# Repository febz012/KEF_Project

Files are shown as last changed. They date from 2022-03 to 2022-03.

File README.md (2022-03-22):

# KEF_Project
This repository consists of a series of IoT projects with LoRA

# 1)  Weather Station 
      A weather station constructed using Industrial grade sensors. 
      The data is collected periodically and transmitted to a capture station using LoRa.
      After the data is received at the capture station using a gateway,it is uploaded to the cloud using a Nodemcu/Raspberry Pi
      
      The following sensor data were collected
      *****************************************
      
      i)    Humidity and Temperature
      ii)   Wind Speed
      iii)  Wind Direction
      iv)   Rain Gauge
      v)    Barometric Pressure
      vi)   Dew Point
      vii)  Air Density
      
      Components used
      ****************
      
      i)    Atmega328P
      ii)   Nodemcu/Raspberry Pi
      iii)  SMD Resistors,Capacitors
      iv)   Max485 TTL Converter Module
      v)    CD4053 triple 2-channel MUX/DEMUX
      vi)   RF Module E32-868T30D
      vii)  Weather Station Sensors (Detailed list provided in repo)

# 2) LIDAR WATER LEVEL MEASURING UNIT
      Measure Water level of a well using Lidar and transmit the data to a capture station via LoRa.
      The data is then uploaded to a Cloud Storage and made availble on Internet.
      
      LIDAR WATER LEVEL MEASURING UNIT
      Measure Water level of a well using Lidar and transmit the data to a capture station via LoRa.
      The data is then uploaded to a Cloud Storage and made availble on Internet.

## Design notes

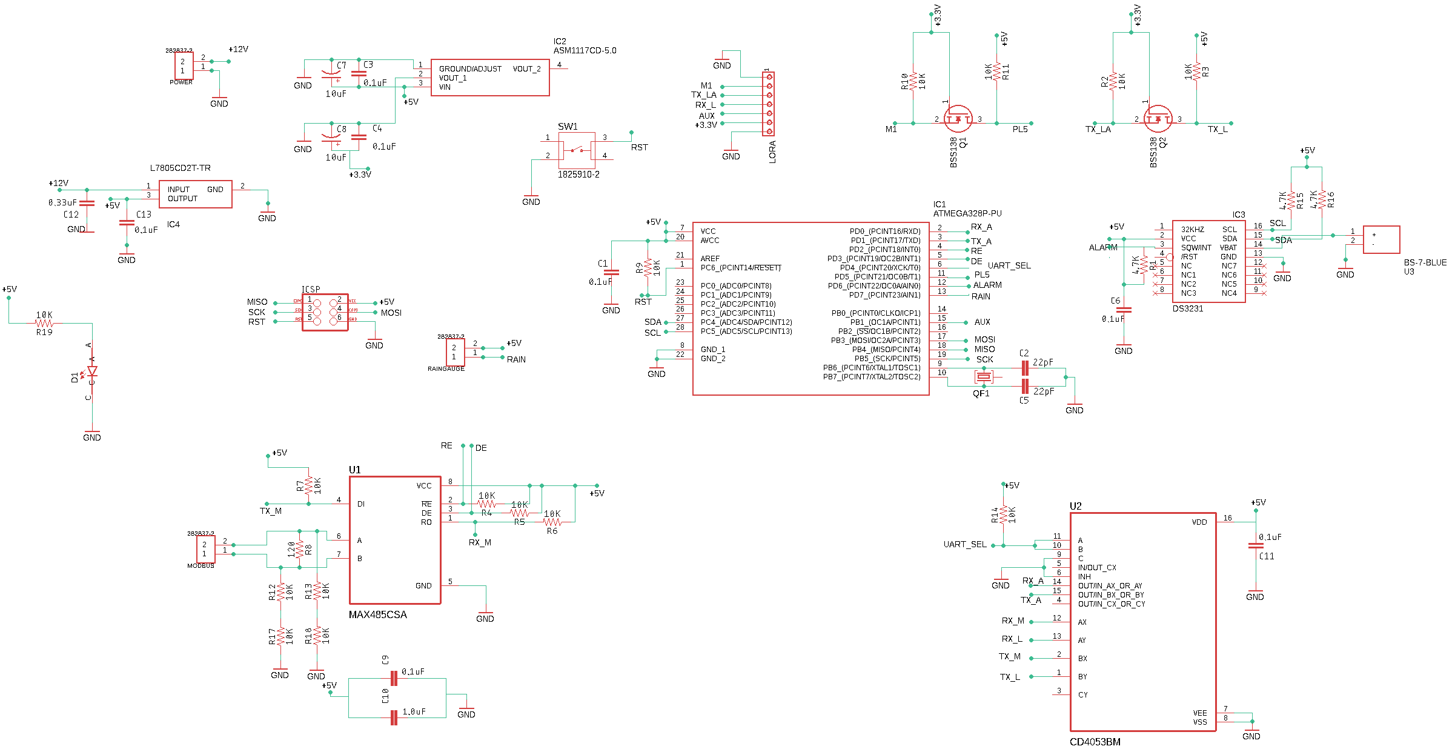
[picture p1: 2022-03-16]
Weather Station Schematic.png

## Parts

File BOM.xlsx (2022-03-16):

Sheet: LIDAR
S.No | Item Name | Rate/Item | Ordered | Delivered | Quantity | GST/Item(18%) | Total/Item (incl GST) | Total (incl GST) | Link
1 | AMS1117-3.3V, 1A, SOT-223 Voltage Regulator IC | 50 | TRUE | TRUE | 1 | 9 | 59 | 59 | https://robu.in/product/ams1117-3-3v-1a-sot-223-voltage-regulator-ic-pack-of-5-ics/
2 | 10uF (10000nF) 50V Capacitor - 0805 SMD Package - 10 Pieces | 20 | TRUE | TRUE | 4 | 3.6 | 23.6 | 94.4 | https://www.electronicscomp.com/10uf-50v-smd-capacitor-0805-package?search=10uf%20smd
3 | 100nF (0.1uF) 50V Capacitor - 0805 SMD Package - 10 Pieces | 20 | TRUE | TRUE | 4 | 3.6 | 23.6 | 94.4 | https://www.electronicscomp.com/100nf-50v-smd-capacitor-0805-package?search=0.1uf%20smd
4 | Solar Power Management Module For 6V~24V Solar Panel | 675 | TRUE | TRUE | 2 | 121.5 | 796.5 | 1593 | https://www.evelta.com/solar-power-management-module-for-6v-24v-solar-panel/#product-reviews
5 | 28 Pin Narrow DIP IC Socket Base Adaptor (Pack of 2) | 7 | TRUE | TRUE | 2 | 1.26 | 8.26 | 16.52 | https://www.electronicscomp.com/28-pin-ic-base-dip?search=28%20pin
6 | LoRa 868MHZ SX1276 Wireless Transmitter and Receiver RF Module E32-868T30D | 1414.41 | TRUE | TRUE | 1 | 254.59 | 1669 | 1669 | https://robu.in/product/lora-868mhz-sx1276-wireless-transmitter-and-receiver-rf-module-e32-868t30d/
7 | 824 – 960 MHz / 1 dBi Gain Rubber Duck Antenna | 50 | TRUE | TRUE | 1 | 9 | 59 | 59 | https://robu.in/product/865-868-mhz-1dbi-gain-rubber-duck-antenna/
8 | 18650 SMD/SMT High-Quality Single Battery Holder | 63.56 | TRUE | TRUE | 1 | 11.44 | 75 | 75 | https://robu.in/product/18650-battery-holder-smd-smt/
9 | SAMSUNG ICR18650-26JM 2600mAh (2C) LI-ION BATTERY | 312.71 | TRUE | TRUE | 1 | 56.29 | 369 | 369 | https://robu.in/product/samsung-2600mah-18650-1s-lithium-ion-cell/
10 | 10K ohm Resistor - 0805 SMD Package - 20 Pieces | 16 | TRUE | TRUE | 3 | 2.88 | 18.88 | 56.64 | https://www.electronicscomp.com/10k-ohm-resistor-0805-smd-package?search=10k%20smd
11 | Micro USB 2.0 B type 5 Pin Connector-5Pcs. | 66.95 | TRUE | TRUE | 1 | 12.05 | 79 | 79 | https://robu.in/product/micro-usb-2-0-b-type-5-pin-connector/
12 | HC49/U 16MHz Crystal Oscillator (Pack of 5) | 50 | TRUE | TRUE | 1 | 9 | 59 | 59 | https://robu.in/product/hc49-s-16mhz-crystal-oscillator-pack-of-5/
13 | 22pF 0805 Surface Mount Multilayer Ceramic Capacitor (Pack of 50) | 21.19 | TRUE | TRUE | 1 | 3.81 | 25 | 25 | https://robu.in/product/22pf-0805-surface-mount-multilayer-ceramic-capacitor-pack-of-50/
14 | Generic 20PCS BSS138 Field Effect Transistor SOT-23 New | 237.29 | TRUE | TRUE | 2 | 42.71 | 280 | 560 | https://www.amazon.in/Generic-BSS138-Effect-Transistor-SOT-23/dp/B0727NP1SZ?hvadid=397009549180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
15 | Push Button Switch 4 Pin - 5mm - 2 Pieces Pack | 5 | TRUE | TRUE | 4 | 0.9 | 5.9 | 23.6 | https://www.electronicscomp.com/push-button-switch-4-pin-5mm?search=push%20button
16 | 10 uF 25V Surface Mount Electrolytic Capacitor (Pack of 20) | 41.53 | TRUE | TRUE | 1 | 7.47 | 49 | 49 | https://robu.in/product/10-uf-25v-surface-mount-electrolytic-capacitor-pack-of-20/
17 | 4 Pin JST XH 2.54mm Pitch Plug and Socket with Cable – 5 Pcs. | 63.56 | TRUE | TRUE | 1 | 11.44 | 75 | 75 | https://robu.in/product/4-pin-jst-xh-2-54mm-pitch-plug-and-socket-with-cable-5-pcs/
18 | 2x3 header(1x40 pin) sponsored | 0 | TRUE | TRUE | 0 | 0 | 0 | 0
19 | 2 Pin JST XH 2.54mm Pitch Plug and Socket with Cable – 10 Pcs. | 59.32 | TRUE | TRUE | 1 | 10.68 | 70 | 70 | https://robu.in/product/2-pin-jst-xh-2-54mm-pitch-plug-and-socket-with-cable-10-pcs/
20 | Heat Shrink Sleeve 4mm Black 2meter Industrial Grade WOER (HST) | 33.05 | TRUE | TRUE | 1 | 5.95 | 39 | 39 | https://robu.in/product/heat-shrink-sleeve-4mm-black-2meter-industrial-grade-woer-hst/
21 | Heat Shrink Tube - 7mm Diameter - Black - 1meter | 28 | TRUE | TRUE | 1 | 5.04 | 33.04 | 33.04 | https://www.electronicscomp.com/heat-shrink-tube-7mm?search=heat%20shrink%207%20mm
22 | Heat Shrink Tube - 3mm Diameter - Black - 1meter | 13 | TRUE | TRUE | 1 | 2.34 | 15.34 | 15.34 | https://www.electronicscomp.com/heat-shrink-tube-3mm?search=heat%20shrink%203%20mm
23 | CentIoT® - RFM95W-868S2 RFM95 LoRa Ultra-long Range Transceiver Module | 1031.36 | TRUE | TRUE |  | 185.64 | 1217 | 1217 | https://www.amazon.in/CentIoT%C2%AE-RFM95W-868S2-Ultra-long-Transceiver-Automated/dp/B07TTBCP14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
24 | LoRa 868MHZ SX1276 Wireless Transmitter and Receiver RF Module E32-868T30D | 1414.41 | TRUE | TRUE | 2 | 254.59 | 1669 | 3338 | https://robu.in/product/lora-868mhz-sx1276-wireless-transmitter-and-receiver-rf-module-e32-868t30d/
25 | GSM External Antenna – 5cm -2G/3G |  | TRUE | TRUE | 3 |  |  | 159.3 | https://www.ktron.in/product/gsm-external-antenna-rubber-duct/
26 | SMD Resistor Kit - 1206 Package - | 823.95 | TRUE | TRUE | 1 | 148.26 | 972 | 972 | https://www.tomsonelectronics.com/
27 | Lithium Coin Cell Battery Holder | 8 | TRUE | TRUE | 5 | 1.44 | 9.44 | 47.2 | https://www.electronicscomp.com/lithium-coin-cell-battery-holder
28 | DS3231 IC - (SMD SOP-16 Package) - I2C Real Time Clock (RTC) IC | 240 | TRUE | TRUE | 1 | 43.2 | 283.2 | 283.2 | https://www.electronicscomp.com/ds3231-i2c-real-time-clock-ic-smd-package
29 | SI2308 MOSFET - (SMD SOT-23 Package) - N-Channel MOSFET | 25 | TRUE | TRUE | 2 | 4.5 | 29.5 | 59 | https://www.electronicscomp.com/si2308-n-channel-mosfet-smd-sot-23-package
30 | PCB | 1113 | TRUE | TRUE | 2 | 400.68 | 2627 | 2627
31 | Solder Paste(150g) |  | TRUE | TRUE |  |  |  | 650
32 | CardBoard
 | Tools
1 | Anti-Static Tweezers 6pcs Set Vetus ESD | 381.36 | TRUE | TRUE | 1 | 68.64 | 450 | 450 | https://robu.in/product/anti-static-tweezers-6pcs-set-vetus-bga-esd/
2 | Mechanic XG-50 50gm SMD Solder Paste | 195 | TRUE | TRUE | 1 | 35.1 | 230.1 | 230.1 | https://www.electronicscomp.com/mechanic-xg-50-50gm-smd-solder-paste?search=solder%20pas
3 | Soldron 8858 Portable Hot Air Blower | 2950 | TRUE | TRUE | 1 | 531 | 3481 | 3481 | https://www.electronicscomp.com/soldron-8858-portable-hot-air-blower?search=soldron
 | Shipping Charges(incl GST)
 | ElectronicsComp | 57.82
 | Amazon | 50
 | ktron | 76.7
 | ElectronicsComp | 57.82
 | Total | 18220.08
 | Tools Used
TRUE | magnifying glass
TRUE | hot air gun
TRUE | screw driver kit
TRUE | Soldering station
TRUE | wick
TRUE | multi meter
TRUE | Power logger
TRUE | nail cutter/Stripper
TRUE | Plier
TRUE | Lighter

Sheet: DataEst
sensor reading size(byte)
per mesg | 122
per day | 2928
per month | 90768
Plan of Action
To Do
 | LIDAR
 | Task | Status | Requirements | Deadline
 | Lidar Range | TRUE | TRUE | ()
 | Lidar I2C Embedded C | TRUE | TRUE
 | RTC I2C in embedded C | TRUE | TRUE
 | LoRa in embedded C | FALSE | FALSE
 | PCB | FALSE | FALSE
 | UART in embedded C | FALSE | FALSE
 | Power Modes AVR | FALSE | FALSE
 | Power Modes LoRa | FALSE | FALSE
 | LoRa GATEWAY
 | Task | Status | Requirements | Deadline
 | IoT Dashboard
 | Task | Status | Requirements | Deadline

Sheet: Bill
Payment 1
Invoice/Order No | Site | Total (incl GST) | Link
#59351 | evelta (https://www.evelta.com/) | 1593 | https://drive.google.com/file/d/1KdoJgUXVntU-fNlz_gL1jmwZUO_TcFWn/view?usp=sharing
#INV2122/83195 | robu (http://robu.in/) | 826 | https://drive.google.com/file/d/1oHZIXf0c9J61X6klJDoy7V-8e50b6eca/view?usp=sharing
#2446352 | electronicscomp (https://www.electronicscomp.com/) | 598.26 | https://drive.google.com/file/d/1tbLNYwT6mN2hFWUBFQRufNEy_DKHh44S/view?usp=sharing
#INV2122/81483 | robu (http://robu.in/) | 2251 | https://drive.google.com/file/d/1dMw9E3V9uXG3P7f6c1kfVkSjADZ8LeMt/view?usp=sharing
#IN734 | amazon (http://amazon.in/) | 560 | https://drive.google.com/file/d/1y0p9wHAtC-Sr6zmesg_EakGdWTt2pKPe/view?usp=sharing
#IN2279 | amazon (http://amazon.in/) | 1599 | https://drive.google.com/file/d/11f2CMFwAEetYzHBXJmnq7jQklrcev7l0/view?usp=sharing |  | (Returned)
Total | 7427.26
Paid | 7500 |  | Balance | 1671.74
Payment 2
Invoice/Order No | Site | Total (incl GST) | Link
#IN2292 | amazon (http://amazon.in/) | 1267 | https://drive.google.com/file/d/1LGcB4qp0G7wk5sOC120geKtzM6_C3leX/view?usp=sharing
#INV2122/86272 | robu (http://robu.in/) | 3338 | https://drive.google.com/file/d/1yQb5bhKW9nLFsLXRsGg9221BV5wP7vXF/view?usp=sharing
#2453223 | electronicscomp (http://electronicscomp.com/) | 3481 | https://drive.google.com/file/d/12iAlyW6fWR3orsmdf0R2yB5cSxVH2dMh/view?usp=sharing
#212202904 | ktron (http://ktron.in/) | 236 | https://drive.google.com/file/d/1wxCk3mkAzIj7MEjpvn-SfSsvTFzV90DO/view?usp=sharing
#2470413 | electronicscomp (http://electronicscomp.com/) | 470.82 | https://drive.google.com/file/d/14QCEx3Z9L_pFN2bxYPmaX1ebwvc7dJfH/view?usp=sharing
#108470 | pcbpower (https://www.pcbpower.com/) | 2627 | https://drive.google.com/file/d/1Ia6PnSgYmulySk9ZU58-H5oNuoiZoH8p/view?usp=sharing
#51635 | tomsonelectronics (https://www.tomsonelectronics.com/) | 972 | https://drive.google.com/file/d/19-z4lsGepoI1Ykm4HPJM7EuQ67hz6QO9/view?usp=sharing
Misc | NA | 650
Amount | 12391.82
Total | 10720.08
Paid | 20000 |  | Balance
Misc
Solder Paste(150g) | 650
CardBoard
Payment 3
 | 1226

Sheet: Weather
S.No | Item Name | Rate/Item | Ordered | Delivered | Quantity | GST/Item(18%) | Total/Item (incl GST) | Total (incl GST) | Link
1 | Waveshare Industrial USB to RS485 Converter
 | SI2308 MOSFET - (SMD SOT-23 Package) - N-Channel MOSFET
 | MAX485 TTL to RS485 Converter Module

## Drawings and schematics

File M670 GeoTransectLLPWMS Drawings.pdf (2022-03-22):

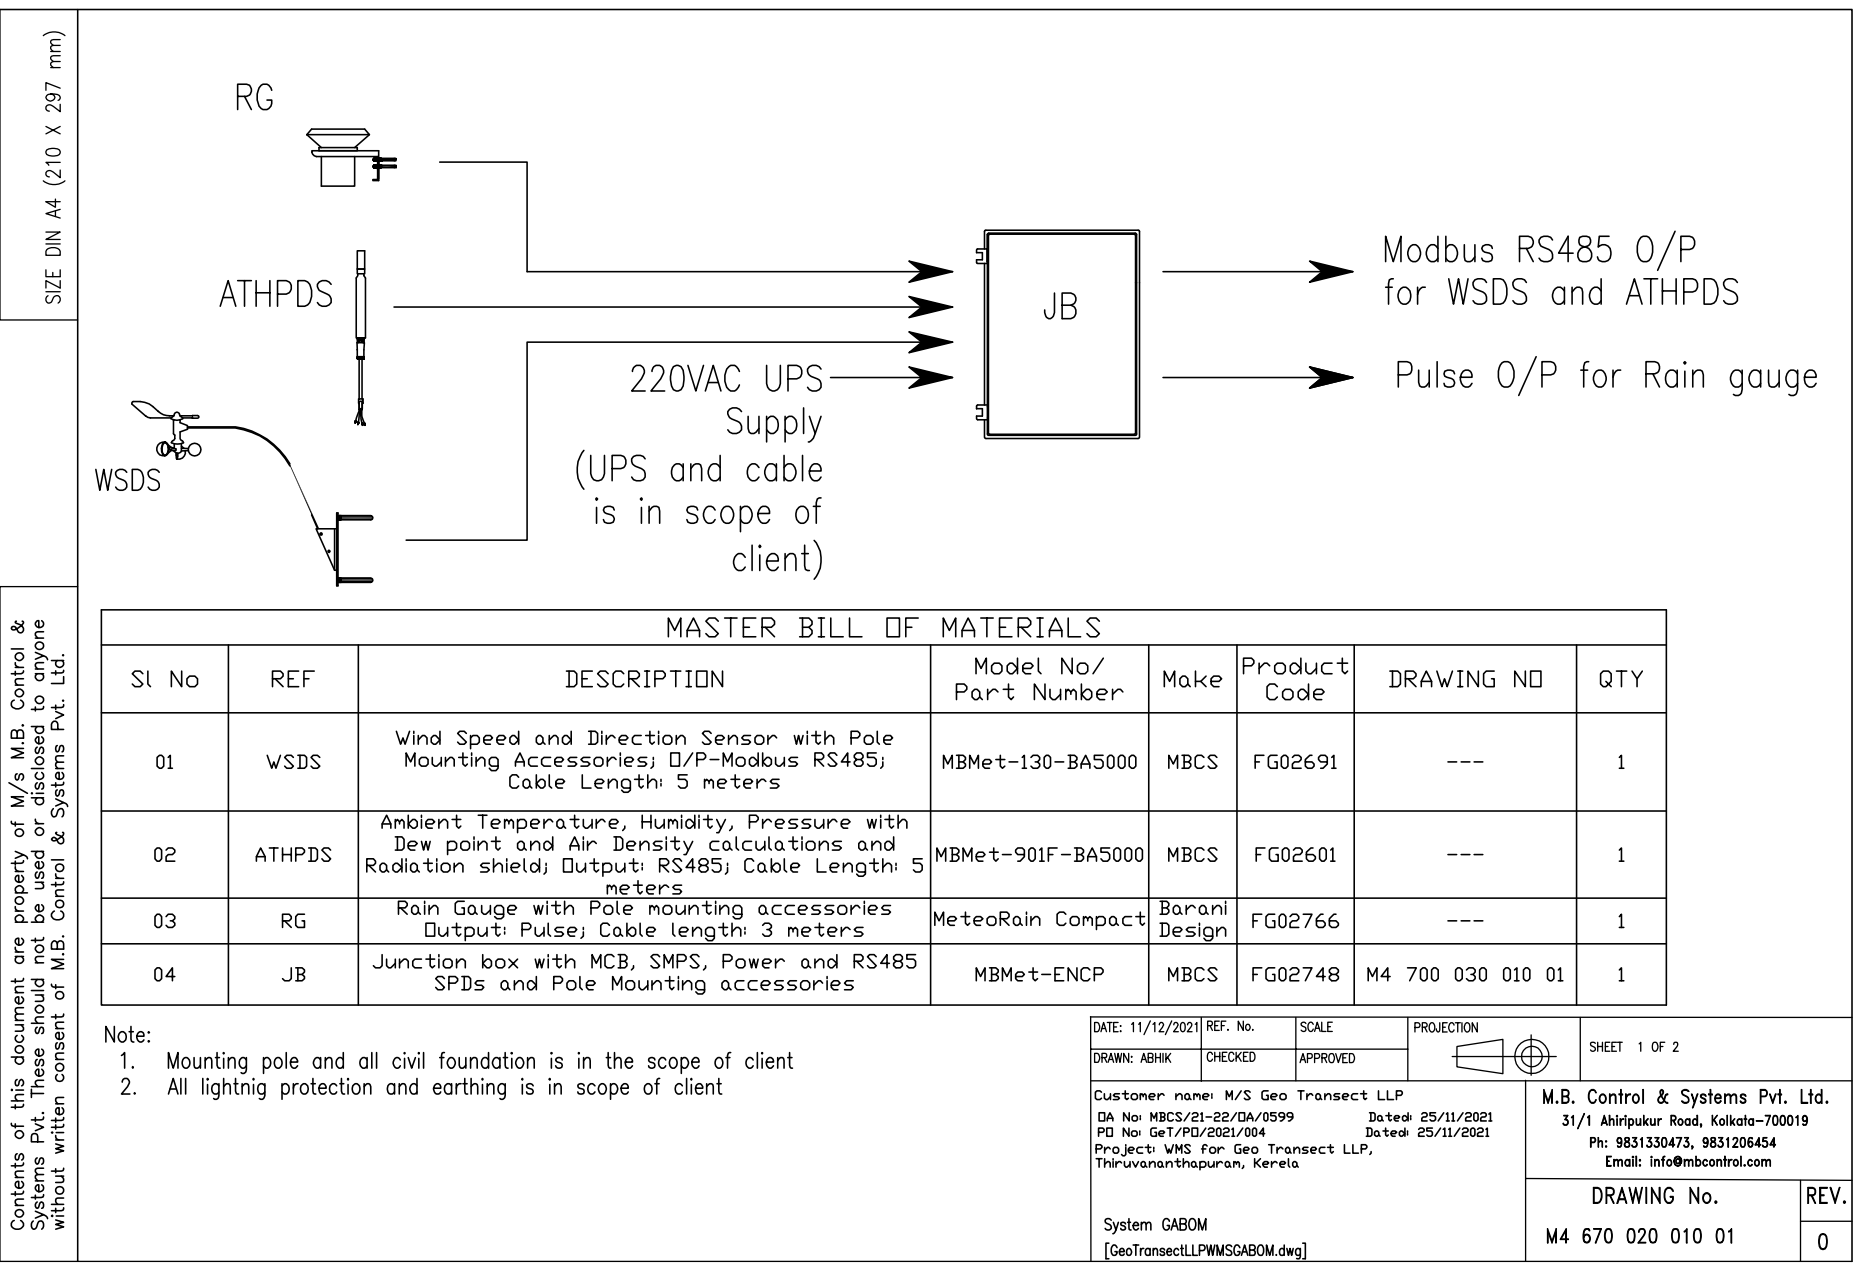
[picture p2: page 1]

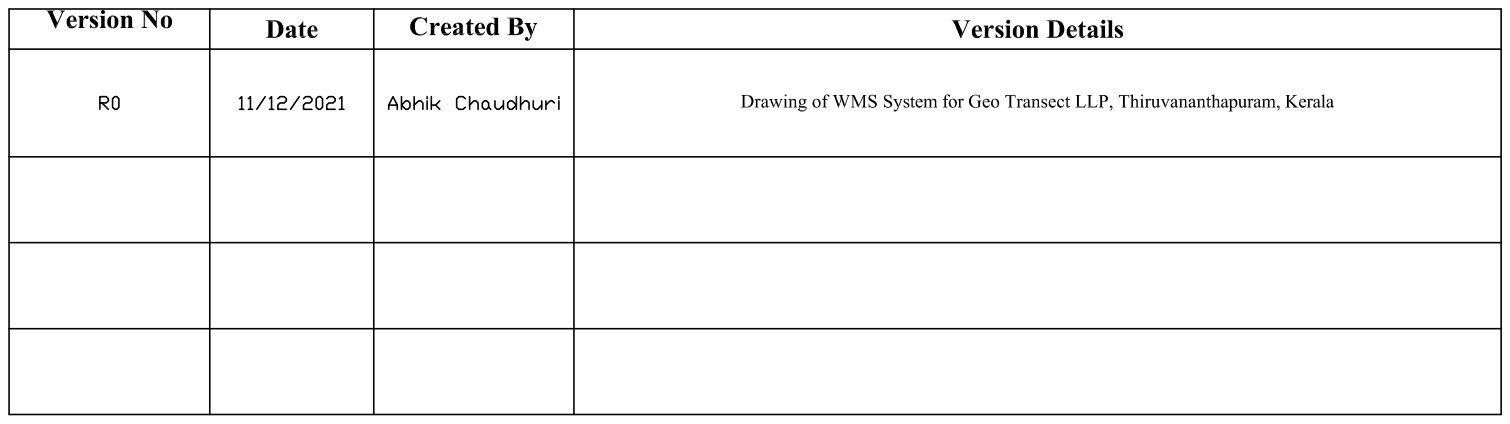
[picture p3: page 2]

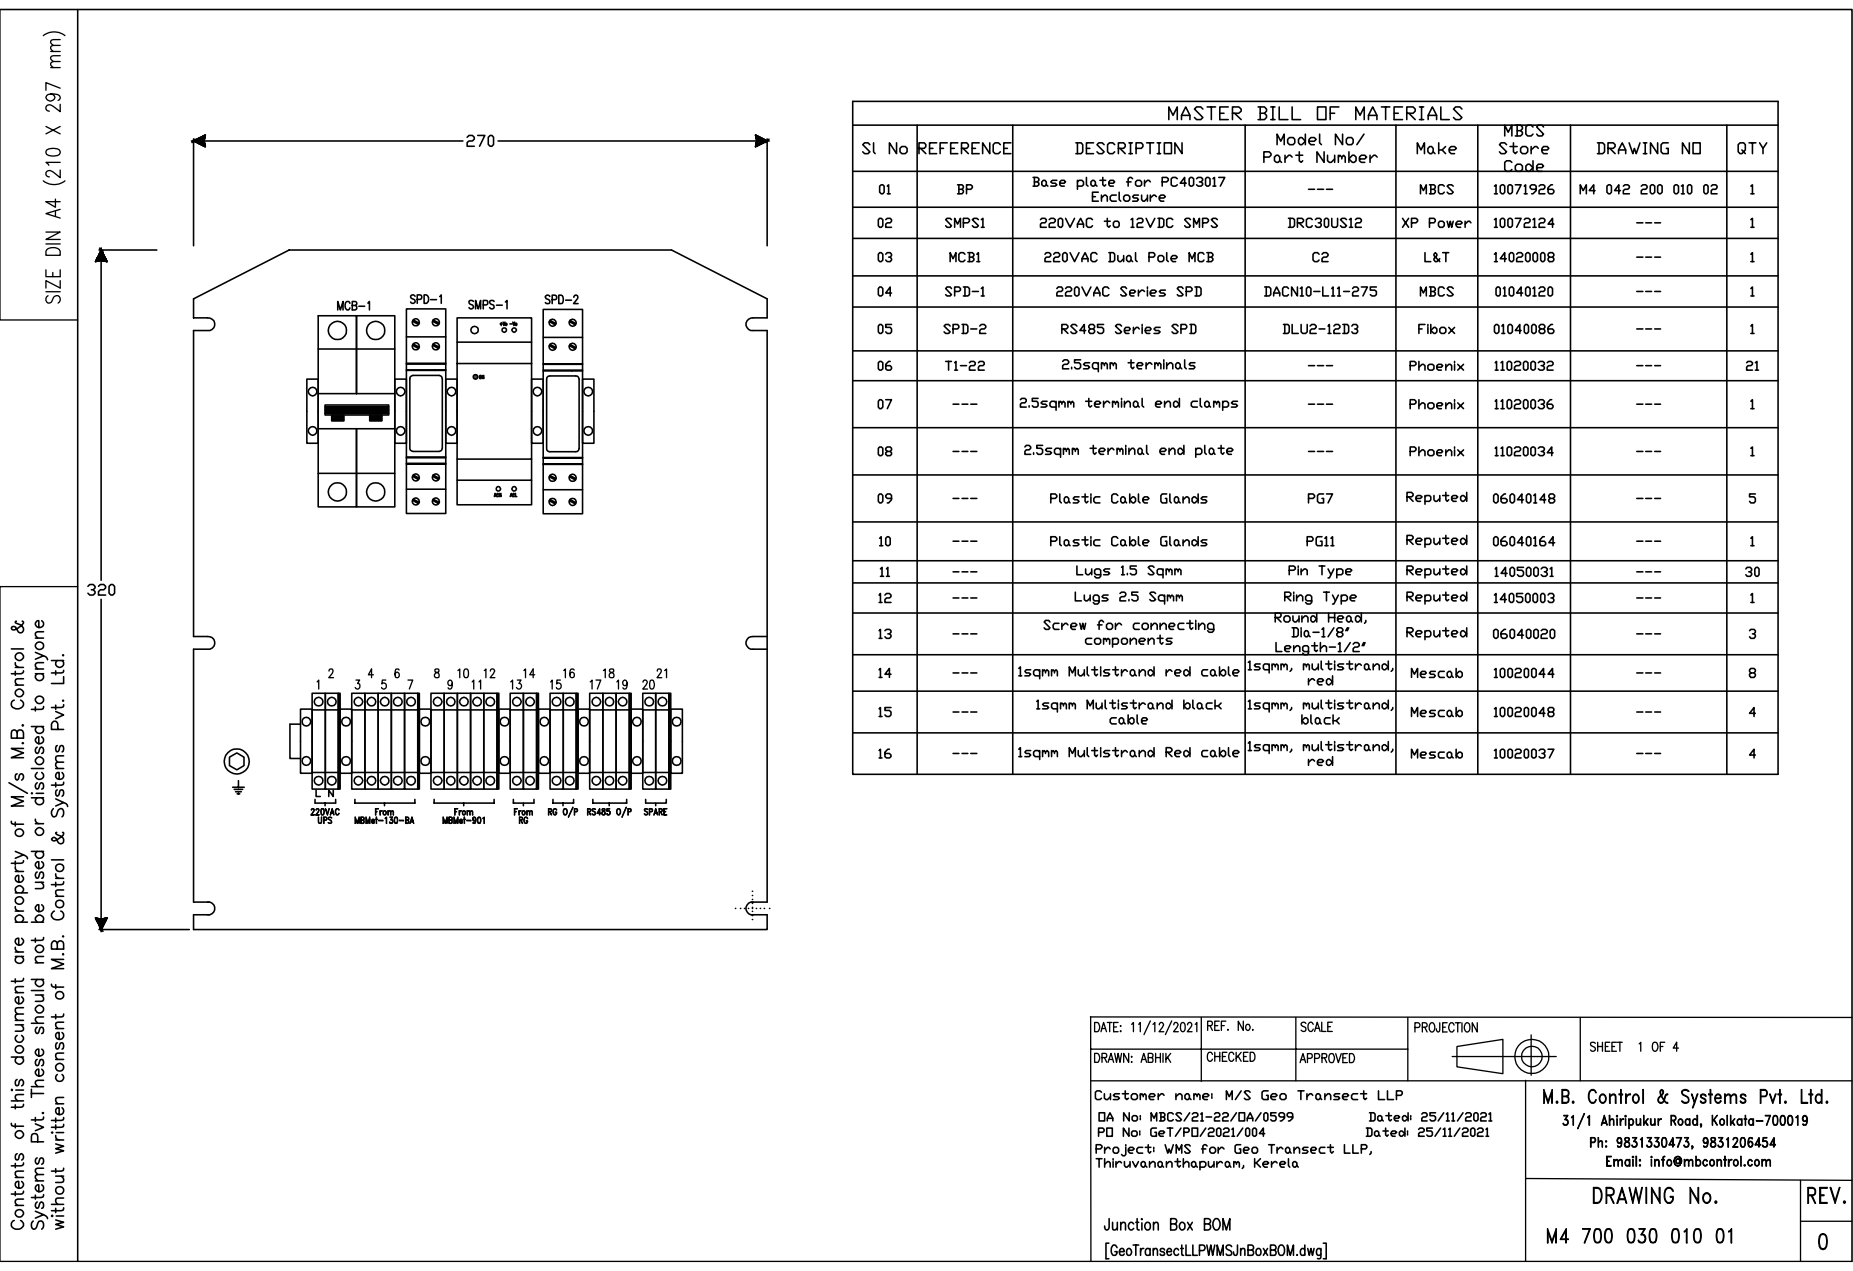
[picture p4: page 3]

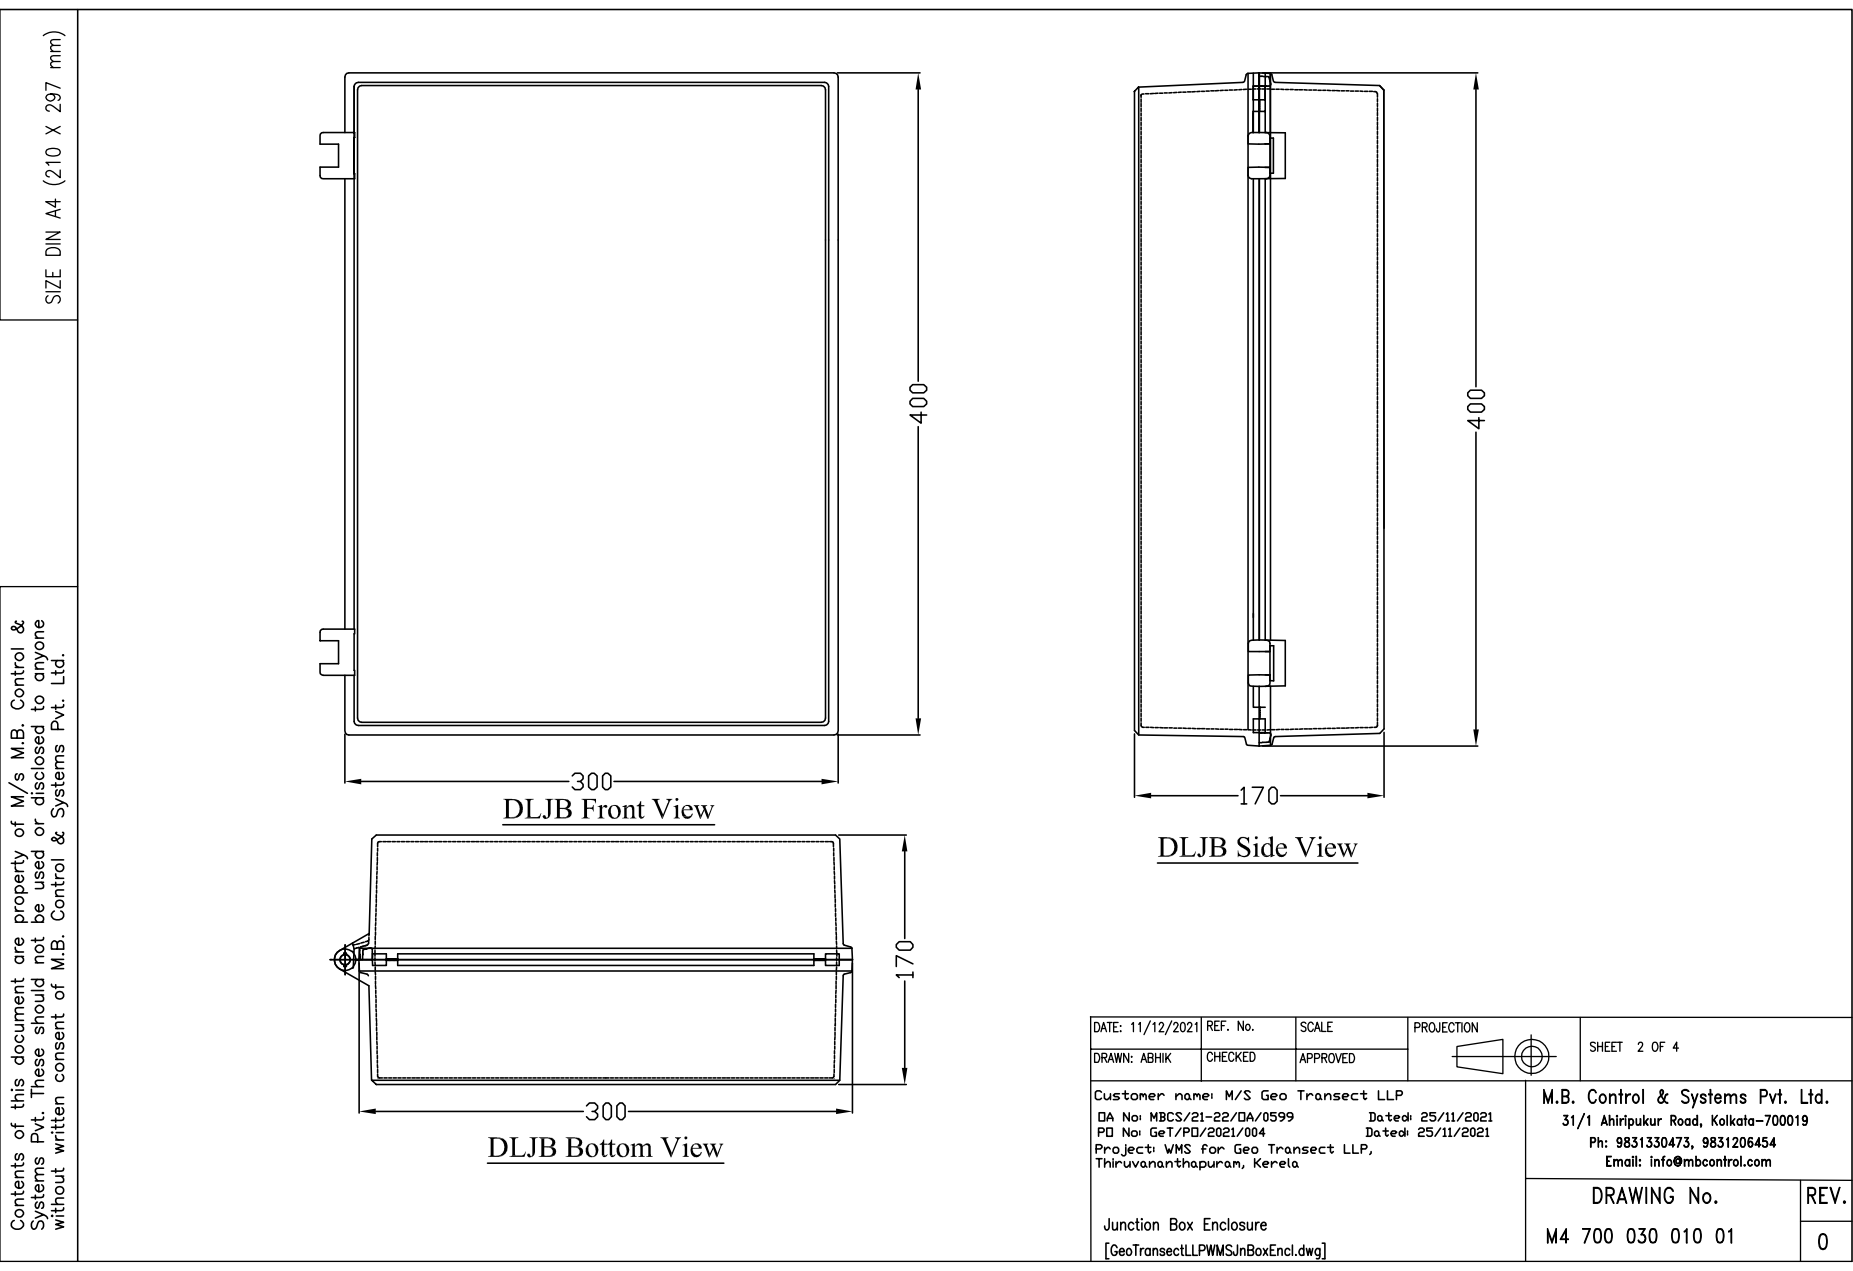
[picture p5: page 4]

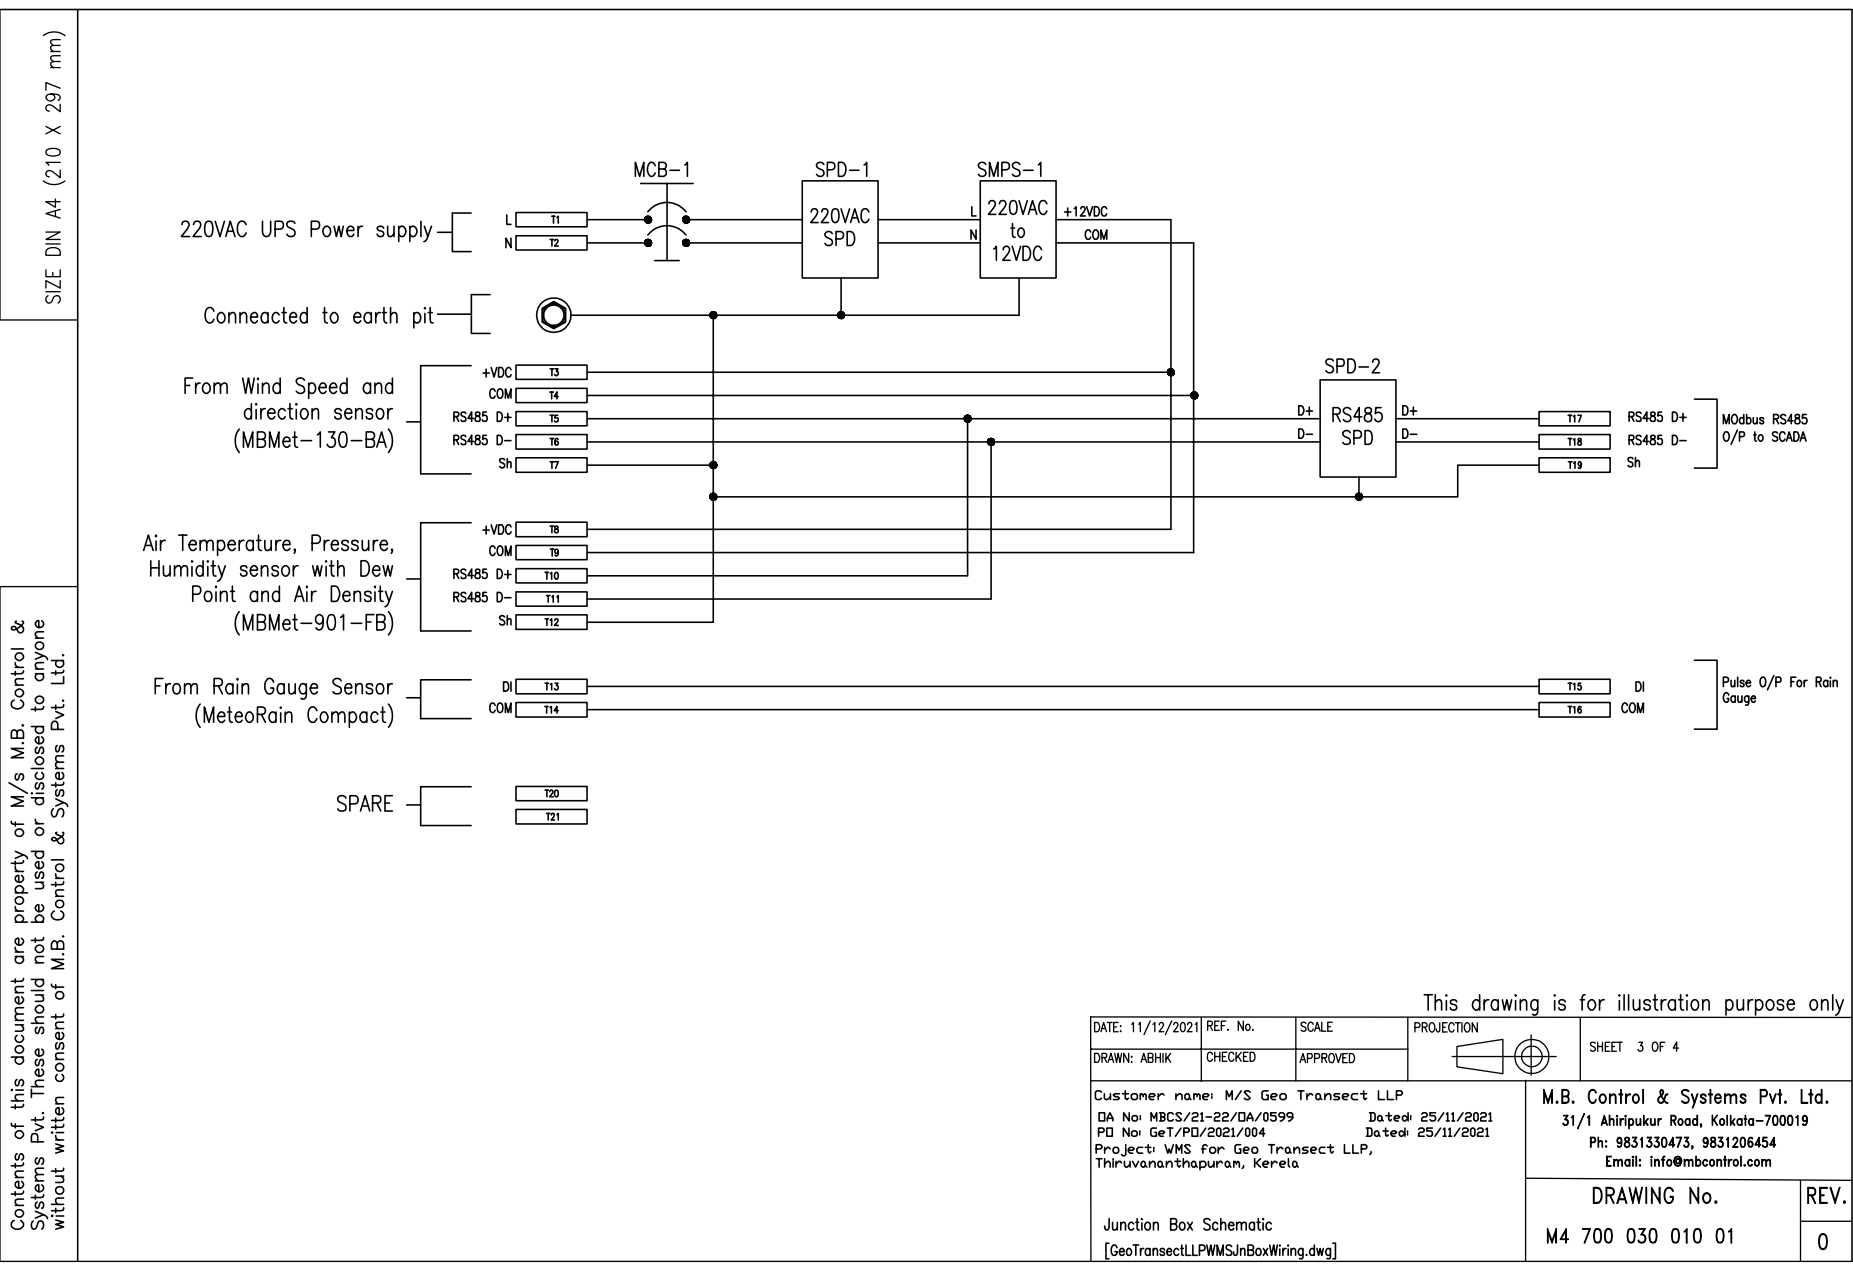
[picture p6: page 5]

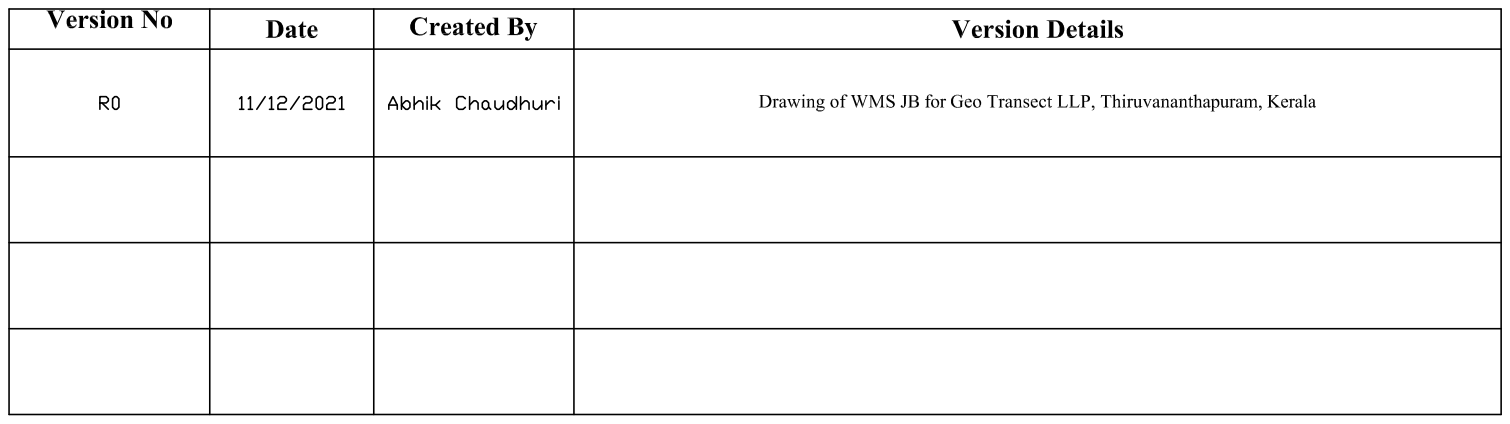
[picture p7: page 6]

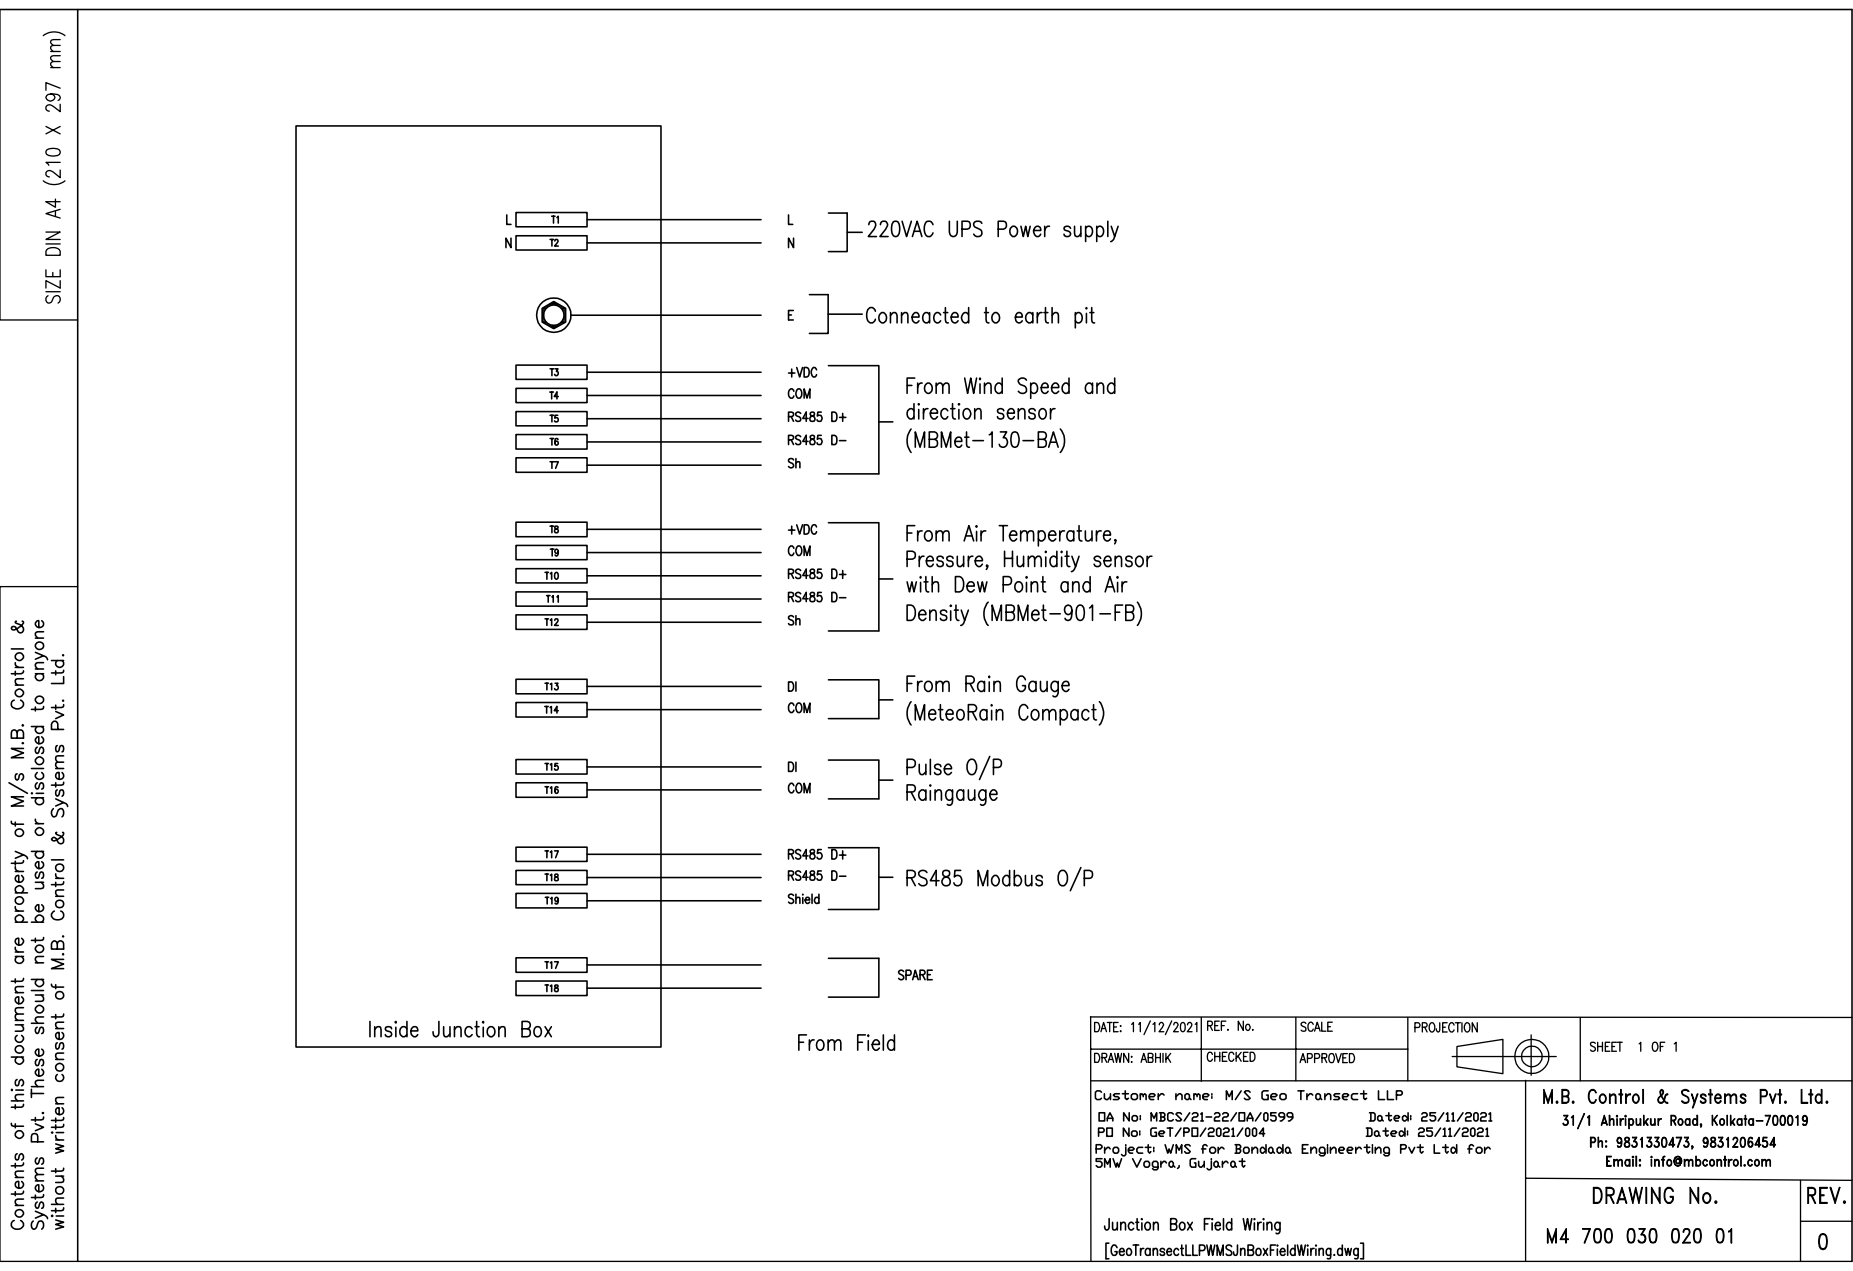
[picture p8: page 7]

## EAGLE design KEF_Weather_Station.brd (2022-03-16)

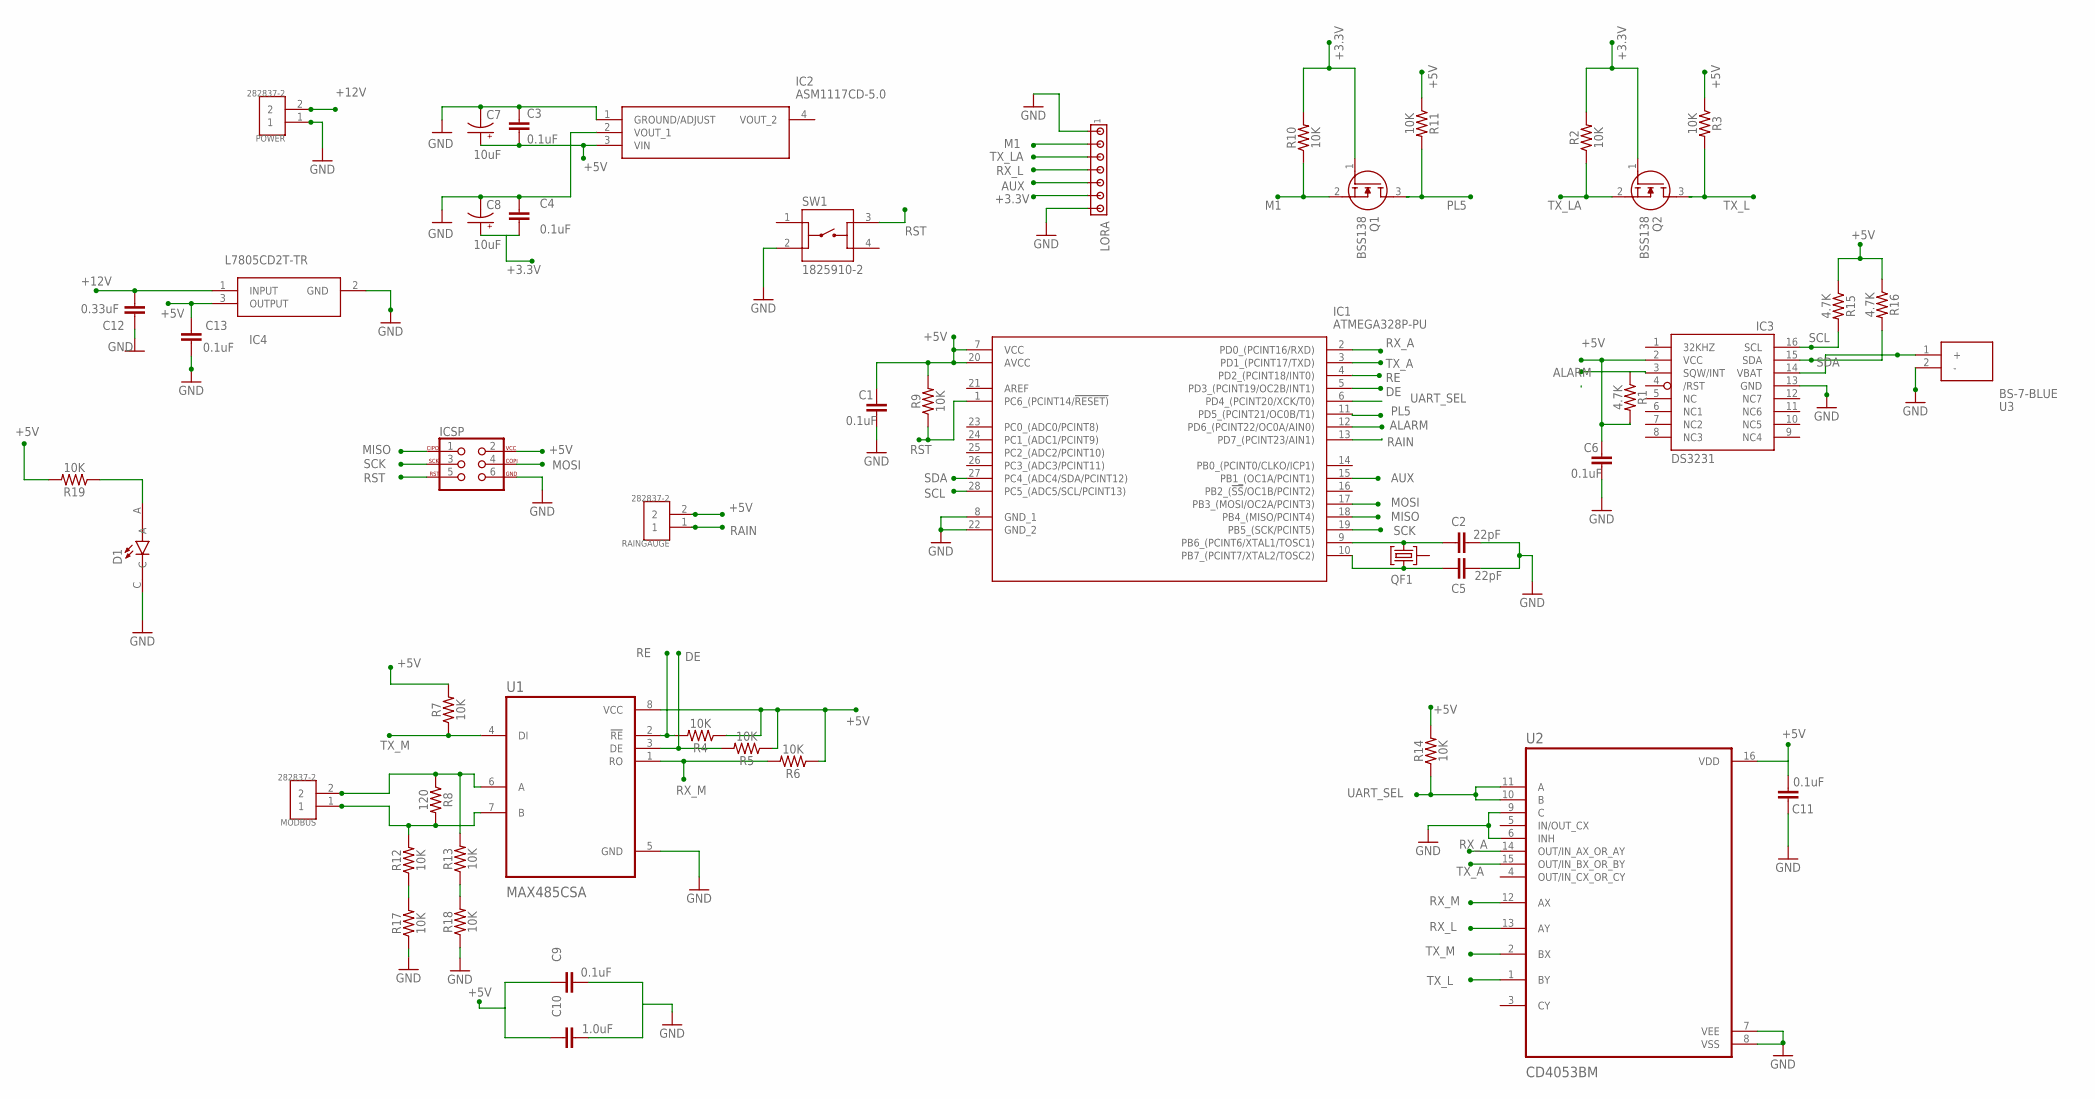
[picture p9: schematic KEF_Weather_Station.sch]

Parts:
C1, C3, C4, C6, C9, C11, C13: 0.1uF; 1206
C2, C5: 22pF; 1206
C7, C8: 10uF; EIA3216
C10: 1.0uF; 1206
C12: 0.33uF; 1206
D1: LTST-C230KFKT; LEDC3216X110
IC1: ATMEGA328P-PU; DIP794W53P254L3467H457Q28N
IC2: ASM1117CD-5.0; SOT229P700X180-4N
IC3: DS3231/SO; SO16W
IC4: L7805CD2T-TR; L7805CD2T
ICSP: AVR_SPI_PROG_3X2NS; 2X3-NS
LORA: MTA07-100; 10X07MTA
MODBUS: 282837-2; TE_282837-2
POWER: 282837-2; TE_282837-2
Q1, Q2: BSS138; SOT95P240X120-3N
QF1: 8M10AHC49T; HC49U
R1, R15, R16: 4.7K; 1206
R2, R3, R4, R5, R6, R7, R9, R10, R11, R12, R13, R14, R17, R18, R19: 10K; 1206
R8: 120; 1206
RAINGAUGE: 282837-2; TE_282837-2
SW1: 1825910-2; TE_1825910-2
U1: MAX485CSA; SOIC127P600X175-8N
U2: CD4053BM; SOIC127P600X175-16N
U3: BS-7-BLUE; BS-7-BLUE_1

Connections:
+3.3V: C4.2, C8.+, LORA.6, Q1.1 (G), Q2.1 (G), R2.2, R10.2
+5V: C1.1, C3.2, C6.1, C7.+, C9.1, C10.1, C11.2, C13.1, IC1.7 (VCC), IC1.20 (AVCC), IC2.3 (VIN), IC3.2 (VCC), IC4.3 (OUTPUT), ICSP.2, R1.2, R3.1, R4.1, R5.1, R6.1, R7.2, R9.2, R11.1, R14.2, R15.1, R16.1, R19.2, RAINGAUGE.2, U1.8 (VCC), U2.16 (VDD)
+12V: C12.1, IC4.1 (INPUT), POWER.2
ALARM: IC1.12 (PD6_(PCINT22/OC0A/AIN0)), IC3.3 (SQW/INT), R1.1
AUX: IC1.15 (PB1_(OC1A/PCINT1)), LORA.5
DE: IC1.5 (PD3_(PCINT19/OC2B/INT1)), R5.2, U1.3 (DE)
GND: C1.2, C2.2, C3.1, C4.1, C5.2, C6.2, C7.-, C8.-, C9.2, C10.2, C11.1, C12.2, C13.2, D1.C, IC1.8 (GND_1), IC1.22 (GND_2), IC2.1 (GROUND/ADJUST), IC2.2 (VOUT_1), IC3.13 (GND), IC4.2 (GND), ICSP.6, LORA.1, LORA.7, POWER.1, R17.1, R18.1, SW1.2, U1.5 (GND), U2.6 (INH), U2.7 (VEE), U2.8 (VSS), U2.9 (C), U3.2 (-)
M1: LORA.2, Q1.2 (S), R10.1
MISO: IC1.18 (PB4_(MISO/PCINT4)), ICSP.1
MOSI: IC1.17 (PB3_(MOSI/OC2A/PCINT3)), ICSP.4
unnamed: R12.1, R17.2
unnamed: IC3.14 (VBAT), U3.1 (+)
unnamed: C5.1, IC1.10 (PB7_(PCINT7/XTAL2/TOSC2)), QF1.1
unnamed: C2.1, IC1.9 (PB6_(PCINT6/XTAL1/TOSC1)), QF1.3
unnamed: R13.1, R18.2
unnamed: D1.A, R19.1
unnamed: MODBUS.1, R8.2, R12.2, U1.7 (B)
unnamed: MODBUS.2, R8.1, R13.2, U1.6 (A)
PL5: IC1.11 (PD5_(PCINT21/OC0B/T1)), Q1.3 (D), R11.2
RAIN: IC1.13 (PD7_(PCINT23/AIN1)), RAINGAUGE.1
RE: IC1.4 (PD2_(PCINT18/INT0)), R4.2, U1.2 (!RE)
RST: IC1.1 (PC6_(PCINT14/!RESET)), ICSP.5, R9.1, SW1.3
RX_A: IC1.2 (PD0_(PCINT16/RXD)), U2.14 (OUT/IN_AX_OR_AY)
RX_L: LORA.4, U2.13 (AY)
RX_M: R6.2, U1.1 (RO), U2.12 (AX)
SCK: IC1.19 (PB5_(SCK/PCINT5)), ICSP.3
SCL: IC1.28 (PC5_(ADC5/SCL/PCINT13)), IC3.16 (SCL), R15.2
SDA: IC1.27 (PC4_(ADC4/SDA/PCINT12)), IC3.15 (SDA), R16.2
TX_A: IC1.3 (PD1_(PCINT17/TXD)), U2.15 (OUT/IN_BX_OR_BY)
TX_L: Q2.3 (D), R3.2, U2.1 (BY)
TX_LA: LORA.3, Q2.2 (S), R2.1
TX_M: R7.1, U1.4 (DI), U2.2 (BX)
UART_SEL: IC1.6 (PD4_(PCINT20/XCK/T0)), R14.1, U2.10 (B), U2.11 (A)

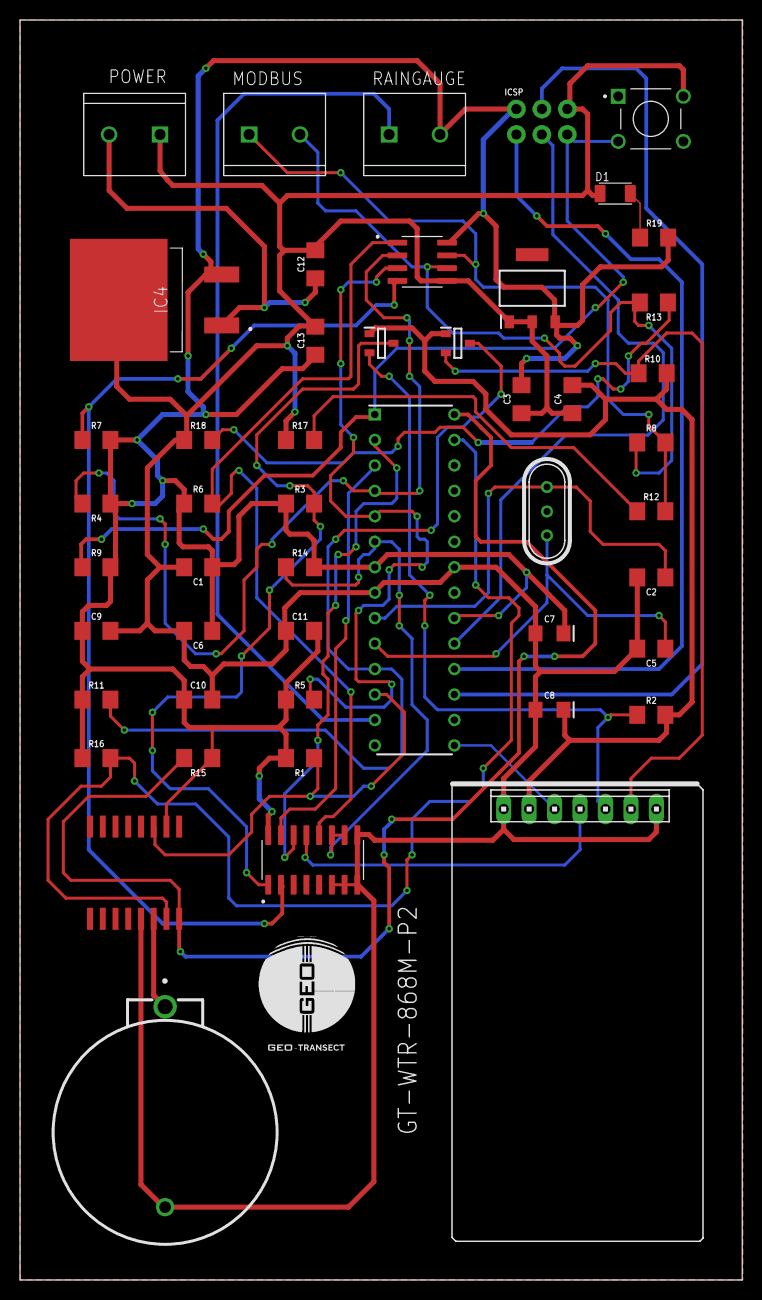
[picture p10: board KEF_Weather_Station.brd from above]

Board: 2 copper layers, 72.1 x 125.7 mm, 49 parts (0 on the bottom side), 33 nets.

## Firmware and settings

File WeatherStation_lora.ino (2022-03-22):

#include <ModbusMaster.h>
#include <RTClib.h>

#define MAX485_DE      3
#define MAX485_RE_NEG  2

ModbusMaster node; //object node for class ModbusMaster for MB-Met 901 FB
ModbusMaster nodewind;
RTC_DS3231 rtc;

static uint32_t i;
uint8_t j, result;
uint16_t data[6];
const int demux = 4;
int lora_int;
int alarm_int;
uint8_t mins;
float val = 0;
DateTime tim;

String weather = "";
String dl = "," ;

void preTransmission()            //Function for setting stste of Pins DE & RE of RS-485
{
  digitalWrite(MAX485_RE_NEG, 1);
  digitalWrite(MAX485_DE, 1);
}
void postTransmission()
{
  digitalWrite(MAX485_RE_NEG, 0);
  digitalWrite(MAX485_DE, 0);
}

void setup()
{
  pinMode(MAX485_RE_NEG, OUTPUT);
  pinMode(MAX485_DE, OUTPUT);
  pinMode(demux, OUTPUT);
  pinMode(5,INPUT);
  pinMode(6,INPUT);
 
  digitalWrite(MAX485_RE_NEG, 0);
  digitalWrite(MAX485_DE, 0);
  Serial.begin(9600);
  mins=0;

  Serial.println("setting up ");
  node.begin(2, Serial);    //Slave ID as 2
  nodewind.begin(1, Serial);
  node.preTransmission(preTransmission);      
  node.postTransmission(postTransmission);
  nodewind.preTransmission(preTransmission);
  nodewind.postTransmission(postTransmission);
  if(!rtc.begin()) {
        Serial.println("Couldn't find RTC!");
        Serial.flush();
        while (1) delay(10);
    }
  rtc.disable32K();
  rtc.clearAlarm(1);
  rtc.clearAlarm(2);
  rtc.writeSqwPinMode(DS3231_OFF);
  rtc.disableAlarm(2);
  rtc.setAlarm1(
            rtc.now() + TimeSpan(10),
            DS3231_A1_Second // this mode triggers the alarm when the seconds match. See Doxygen for other options
    ) ;
}

float gsr(int addr)  // #######  gsr (get sensor reading) ###############
{
  digitalWrite(demux, LOW); delay(100);
  result = node.readHoldingRegisters(addr,2); // addr =20
  if (result == node.ku8MBSuccess)
  {
    for (j = 0; j < 2 ; j++)
      data[j] = node.getResponseBuffer(j);
    memcpy(&val, data, 4);
    digitalWrite(demux, HIGH); delay(100);
    weather.concat(String(val, 4)+ dl);
  }
  delay(100);
  return val;
}

float wsr(int addr)  // #######  wsr (wind sensor reading) ###############
{
  digitalWrite(demux, LOW); delay(100);
  result = nodewind.readHoldingRegisters(addr,1);
  if (result == nodewind.ku8MBSuccess)
  {
    data[0] = nodewind.getResponseBuffer(0);
    digitalWrite(demux, HIGH); delay(100);
    weather.concat(String(data[0])+ dl);
  }
  delay(100);
  return val;
}

void loop()
{
  lora_int=digitalRead(5);
  alarm_int=digitalRead(6);
  if(lora_int==0 || alarm_int==0){
  if(rtc.alarmFired(1)) {
        rtc.clearAlarm(1);
        tim=rtc.now();
        int y = tim.year();int mon= tim.month();int d= tim.day(); int h= tim.hour();int minu= tim.minute();int s= tim.second();
        minu = minu + 2;
        if (minu >= 60) minu = minu - 60;
        rtc.setAlarm1(
            DateTime(y, mon, d, h, minu, s),
            DS3231_A1_Minute // this mode triggers the alarm when the seconds match. See Doxygen for other options
            ) ;
        
    }

  gsr(20); //temperature
  gsr(22); //dew point
  gsr(24); //pressure
  gsr(26); //humidty
  gsr(28); //density
  wsr(0);  // wind speed
  wsr(1);  //wind direction
  Serial.println();
  Serial.println(weather);
  char date[10] = "hh:mm:ss";
  rtc.now().toString(date);
  Serial.println(date);
  weather = "";
  
  delay(10000);
  }
  
}

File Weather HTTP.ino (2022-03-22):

#include "WiFi.h"
#include "HTTPClient.h"
#include <ArduinoJson.h>
const char* ssid = "Tgeo";
const char* password = "90206087";
String sensorData = "";
bool ser = false;

int cnt;
void setup() {
  Serial.begin(9600);
  WiFi.begin(ssid, password);
  Serial.print(" Connecting to WiFi ");
  while (WiFi.status() != WL_CONNECTED) {
    delay(500);
    Serial.print(".");
  }
  Serial.println("Connected to the WiFi network");
cnt=62;
}

void loop() {
  /*
  while (Serial.available())
  {
    //Serial.println(cnt);
    sensorData.concat(char(Serial.read()));
    ser = true;
    cnt=cnt+1;
  }
  */
  if (cnt==62)
  {
    StaticJsonDocument<200> doc;
    // Add values in the document
    //
    doc["temp"] = 123.11;
    doc["hum"] = 1351824120;
    //Serial.println("Data to be sent : ");
    //Serial.println(sensorData);
    String requestBody;
    serializeJson(doc, requestBody);
    Serial.println("Data");
    if (WiFi.status() == WL_CONNECTED) {

      HTTPClient http;

      http.begin("http://192.168.1.5:8000/api/");
      delay(1000);
      http.addHeader("Content-Type", "application/json");

      int httpResponseCode = http.POST(requestBody);

      if (httpResponseCode > 0) {
        String response = http.getString();
        Serial.println(httpResponseCode);
        Serial.println(response);
      }
      else {
        Serial.print("Error on sending PUT Request: ");
        Serial.println(httpResponseCode);
      }
      http.end();
    } else {
      Serial.println("Error in WiFi connection");
    }
    sensorData = "";
    //cnt=0;
  }
}

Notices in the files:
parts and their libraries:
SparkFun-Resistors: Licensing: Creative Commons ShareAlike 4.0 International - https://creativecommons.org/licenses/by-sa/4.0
